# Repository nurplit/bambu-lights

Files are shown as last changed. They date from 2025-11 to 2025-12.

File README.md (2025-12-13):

# 🎨 Bambu Lights - Advanced LED Controller

An ESP32-based smart LED controller that brings your Bambu Lab 3D printer to life with dynamic status lighting. Features dual LED strip support, progress visualization beacon, smart chamber light control, and comprehensive printer state tracking via MQTT.

**Inspired by:** [BambuLights by judge2005](https://github.com/judge2005/BambuLights)




---

## 📺 Demo

### Beacon LED Effects
<p align="center">
  Progress Bar Effect
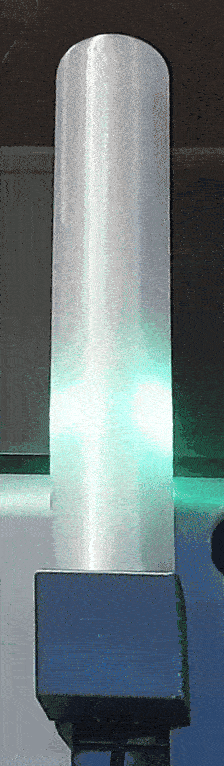
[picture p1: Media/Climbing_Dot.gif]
Climbing Dot Effect
  
  Beacon Animation
</p>

*Main LED strip demo coming soon!*

## ✨ Features

### � LED Control
- **Dual LED Strip Support** - Main status strip + optional progress beacon strip
- **Multiple Modes** - Auto-cycle, Manual color, Printer status, or Off
- **RGBW Support** - Optimized white channel for SK6812 RGBW LEDs
- **Custom Effects** - Solid, Blink, Breathe, Pulse, Progress Bar, Rainbow
- **Per-State Customization** - Different colors and effects for each printer state

### 📊 Printer Status Tracking
- **Real-time MQTT Integration** - Secure SSL/TLS connection to Bambu Lab printer
- **Comprehensive State Detection** - Idle, Heating, Printing, Paused, Complete, Error, Failed
- **Progress Visualization** - Progress bar effect shows print completion
- **Layer Tracking** - Displays current layer and total layers
- **Temperature Monitoring** - Bed and nozzle temperature display

### 🎯 Beacon LED Strip (Optional Second Strip)
- **Progress Bar Animation** - Fills from bottom to top with climbing pixel
- **Climbing Dot Effect** - Single LED climbs the strip
- **Gradient Fill** - Smooth color transition as print progresses
- **Pulsing Effect** - Breathing animation at current progress level
- **Heating Color Override** - Beacon uses heating color during warmup phase

### 🚪 Smart Automation
- **Door Detection** - Auto-responds to printer door open/close
- **Door Protection** - Prevents LED flicker during jogging with door open
- **Chamber Light Sync** - Controls printer chamber light based on printing color
- **LiDAR Pause** - Disables LEDs during LiDAR scanning to prevent interference
- **Auto-Off Timer** - Lights turn off X minutes after print completes (20-120 min)
- **Timelapse Detection** - Maintains proper lighting during timelapse recording

### 🌐 Web Interface
- **Modern Dark UI** - Beautiful responsive web interface with live updates
- **WiFiManager Integration** - Captive portal for easy first-time WiFi setup
- **OTA Updates** - Wireless firmware updates via mDNS hostname
- **Configuration Management** - All settings configurable via web UI
- **Serial Monitor** - Built-in web-based logging for debugging
- **Web Logs** - Access logs remotely at `http://your-device-ip/logs`
- **Telnet Support** - Remote serial monitoring via Telnet (port 23)
- **MQTT Debug Mode** - Toggle full payload logging for troubleshooting
- **Status Dashboard** - Real-time printer and system status display

## 🚀 Quick Start

### Hardware Requirements

#### Required Components
- **ESP32 Development Board** (ESP32-DevKitC, ESP32-WROOM-32, or compatible)
- **Addressable LED Strip** (WS2811, WS2812B, WS2813, SK6812, SK6812 RGBW, APA102, or APA106)
- **Power Supply** (5V DC, rated for your LED count - typically 60mA per LED at full white)
- **Jumper Wires** (3-4 wires depending on setup)

#### Optional Components
- **Second LED Strip** (Beacon progress visualization strip - same types as above)
  - **Recommended:** 10 pixels for optimal beacon effects
- **Logic Level Shifter** (if experiencing signal issues - 3.3V to 5V)
- **Capacitor** (1000µF, 6.3V or higher - smooths power fluctuations)

#### 3D Printed Enclosure
STL and Fusion 360 files included for ESP32 enclosure that mounts to the [BLV AMS Riser for X1C](https://makerworld.com/en/models/19535-blv-ams-ams-2-riser-for-x1c-p1s-p2s-v4#profileId-19420). Files located in `Enclosure/` folder.

### Wiring Diagram

#### Single LED Strip (Main Status)
```
ESP32 GPIO 2  ──→  LED Strip Data In
ESP32 GND     ──┐
                ├──→  LED Strip GND
Power Supply - ─┘
Power Supply + ────→  LED Strip VCC (5V)
```

#### Dual LED Strips (Main + Beacon)
```
ESP32 GPIO 2   ──→  Main LED Strip Data In
ESP32 GPIO 14  ──→  Beacon LED Strip Data In
ESP32 GND      ──┐
                 ├──→  Both LED Strips GND
Power Supply -  ─┘
Power Supply +  ────→  Both LED Strips VCC (5V)
```

> ⚠️ **Important:** Never power LED strips directly from ESP32 pins! Always use an external 5V power supply rated for your LED count. Connect all grounds together (ESP32 GND + LED GND + Power Supply GND).

### Installation

#### 1. Install PlatformIO
- Install [VS Code](https://code.visualstudio.com/)
- Install [PlatformIO IDE](https://platformio.org/platformio-ide) extension in VS Code

#### 2. Clone Repository
```bash
git clone https://github.com/YOUR_USERNAME/bambu-lights.git
cd bambu-lights
```

#### 3. Upload Filesystem (GIF Animations)
```bash
# Upload beacon animation GIFs to ESP32 filesystem
pio run --target uploadfs
```

#### 4. Flash Firmware
```bash
# Build and upload firmware
pio run --target upload

# Monitor serial output (optional)
pio device monitor
```

#### 5. First Boot Setup
1. ESP32 creates WiFi Access Point: `Bambu-Lights-XXXXXX`
2. Connect to this AP with your phone/computer
3. Captive portal opens automatically (or visit `192.168.4.1`)
4. Enter your WiFi SSID and password
5. Device connects and shows IP address in serial monitor

#### 6. Configure Printer
1. Open web browser to `http://bambu-lights-XXXXXX.local/` or the IP address
2. Click **Config** button
3. Enter your printer settings:
   - **Printer IP:** Your Bambu Lab printer's local IP address
   - **Access Code:** From Bambu Handy app (Settings → Lan Mode → Access Code)
   - **Serial Number:** From printer (Settings → Device → Serial Number)
4. Configure LED settings:
   - **Main LED Pin:** GPIO pin number (default: 2)
   - **LED Count:** Number of LEDs in your strip
   - **LED Type:** WS2811, WS2812B, WS2813, SK6812, SK6812 RGBW, APA102, or APA106
   - **Color Order:** GRB, RGB, etc. (depends on your LED type)
5. (Optional) Configure Beacon LED strip with same settings
6. Click **Save & Restart**

> 💡 **Tip:** Use the serial monitor to see connection status and debug any issues

## 🎛️ Web Interface

Access at `http://bambu-lights-XXXXXX.local/` or the IP shown in serial monitor.

### Mode Control
- **Printer Status Mode** - LEDs respond to printer state (Idle, Heating, Printing, Paused, Complete, Error)
- **Auto-Cycle Mode** - LEDs cycle through colors automatically
- **Manual Mode** - Set a custom solid color
- **Off Mode** - All LEDs off (timers and door lights still active)

### Printer Status LED Behavior
Customize colors, brightness, and effects for each printer state:
- **Idle** - Printer ready (default: blue)
- **Heating** - Bed/nozzle warming up (default: red)
- **Printing** - Active print (default: green)
- **Paused** - Print paused (default: yellow)
- **Complete** - Print finished (default: white)
- **Error** - Printer error (default: red blink)

Each state supports multiple effects:
- Solid, Blink, Breathe, Pulse, Progress Bar, Rainbow

### Beacon Settings (Optional Second Strip)
- **Enable/Disable** - Toggle beacon LED strip
- **Effect Selection** - Progress Bar, Climbing Dot, Gradient Fill, Pulsing
- **Color Customization** - Start color, end color (gradient), climb color
- **Brightness Control** - Independent brightness setting
- **GPIO Pin** - Configurable pin assignment

### Quick Controls
- **Door Lights** - Auto white lights when door opens (configurable color)
- **Chamber Light Sync** - Controls printer chamber light:
  - Auto-on during timelapse recording
  - Smart control: ON for white printing colors, OFF for colored filaments
- **LiDAR Pause** - Turns off LEDs during LiDAR scanning
- **Auto-Off Timer** - Lights turn off X minutes after print completes
  - Timer starts when print finishes
  - Lights stay on during active printing
  - Timer restarts if door opened

### System Status
Real-time display of:
- ESP32 WiFi signal, uptime, free memory
- MQTT connection status
- Current LED mode and settings
- Printer state (online/offline, temperatures, progress, layer count)
- Door status
- Timer status (active/inactive, time remaining)

### Serial Monitor & Remote Logging
Built-in logging accessible three ways:

1. **Web Interface** - Serial monitor panel on main page with auto-refresh
2. **Direct URL** - Access logs at `http://your-device-ip/logs` via any browser
3. **Telnet** - Connect via Telnet for real-time streaming logs:
   ```bash
   telnet your-device-ip 23
   ```

Logged events include:
- Connection events
- MQTT messages
- State changes
- Error messages
- Toggle MQTT debug mode for full payload logging (15KB+ per message)

## � Advanced Features

### Smart Chamber Light Control
The system intelligently manages your printer's chamber light:
- **Timelapse Mode** - Auto-on during timelapse recording
- **Color-Aware Control** - Prevents chamber light from washing out custom LED colors:
  - **White filament (255,255,255)** → Chamber light ON
  - **Colored filament** → Chamber light OFF
- **Dynamic Updates** - Responds to printing color changes mid-print

### Door Open Protection
Sophisticated door detection with multiple benefits:
- **Bidirectional Detection** - Accurately tracks door open AND close states
- **Flicker Prevention** - LEDs don't change during jogging operations with door open
- **Automatic Restoration** - LEDs restore to printer state when door closes
- **Timer Integration** - Auto-off timer restarts when door opened

### Progress Beacon Animations
Four unique visualization effects for the optional beacon strip:

1. **Progress Bar** - Green bar fills from bottom to top with white climbing pixel
2. **Climbing Dot** - Single LED climbs up the strip
3. **Gradient Fill** - Smooth color transition (customizable start/end colors)
4. **Pulsing** - Breathing animation at current progress level

All effects show real-time print progress and automatically adapt to heating/printing states.

### RGBW LED Optimization
Special support for SK6812 RGBW LEDs:
- Dedicated white channel for true white output
- Automatic RGBW pixel allocation
- Optimized memory usage for large LED counts

---

## 📊 Technical Details

### System Requirements
- **ESP32**: ESP32-DevKitC or compatible (240MHz dual-core, 320KB RAM, 4MB Flash minimum)
- **Memory**: ~120KB free RAM during operation
- **Power**: 5V/2A minimum for small setups, calculate 60mA per LED at full white for larger installations
- **Network**: 2.4GHz WiFi (ESP32 doesn't support 5GHz)

### Performance Specifications
- **LED Update Rate**: 30 FPS
- **MQTT Latency**: <500ms typical response time
- **Web Interface Load Time**: 2-5 seconds
- **Memory Management**: Chunked HTTP transfer prevents fragmentation
- **Uptime**: Stable operation for weeks with proper power supply

### Supported LED Types
- **WS2811** (RGB) - 5V LED strips, common in older/budget setups
- **WS2812B** (RGB) - Most common, affordable, integrated controller
- **WS2813** (RGB) - Backup data line for reliability
- **SK6812** (RGB or RGBW) - Better color accuracy, true white with RGBW
- **APA102** (RGB) - SPI-based, faster refresh rates
- **APA106** (RGB) - Alternative to WS2812B

### Color Order Options
Configure in web interface to match your specific LED strip:
- GRB (most common for WS2812B)
- RGB
- BGR
- BRG
- RBG
- GBR

---

## 🐛 Troubleshooting

### LEDs Not Responding
**Symptoms:** LEDs stay off or show wrong colors

**Solutions:**
1. Check wiring:
   - ESP32 GND → LED Strip GND → Power Supply GND (all connected)
   - ESP32 GPIO pin → LED Strip Data In
   - Power Supply 5V → LED Strip VCC
2. Verify power supply capacity (60mA × LED count)
3. Try different color order setting (web config → LED Settings)
4. Use logic level shifter if LED strip requires 5V data signal
5. Add 470Ω resistor between ESP32 GPIO and LED data line
6. Add 1000µF capacitor between LED VCC and GND

### WiFi Connection Issues
**Symptoms:** Can't connect to WiFi, AP mode doesn't appear

**Solutions:**
1. Ensure WiFi network is 2.4GHz (ESP32 doesn't support 5GHz)
2. Check WiFi credentials in serial monitor
3. Factory reset: Hold GPIO 0 button during boot for 5 seconds
4. Look for AP: `Bambu-Lights-XXXXXX` (last 6 chars of MAC address)
5. Strong WiFi signal required - ESP32 antenna is small
6. Restart router if connection fails repeatedly

### MQTT Connection Failures
**Symptoms:** "MQTT disconnected" in serial monitor, printer status not updating

**Solutions:**
1. Verify printer IP address is correct (check router DHCP)
2. Confirm access code from Bambu Handy app (Settings → LAN Mode)
3. Ensure printer serial number is accurate (Settings → Device)
4. Check printer is on same network as ESP32
5. Enable LAN Mode on printer if not already enabled
6. Printer must be powered on and connected to WiFi
7. Check firewall isn't blocking port 8883 (MQTT SSL)

### Web Interface Problems
**Symptoms:** Page won't load, hangs, or shows errors

**Solutions:**
1. Try IP address instead of mDNS hostname
2. Find IP in serial monitor: `IP: 192.168.x.x`
3. Clear browser cache (Ctrl+Shift+Del)
4. Try different browser (Chrome/Firefox recommended)
5. Disable browser extensions that might interfere
6. Check ESP32 free memory in status panel (should be >100KB)
7. Reboot ESP32 if memory is low

### Memory Issues
**Symptoms:** ESP32 reboots, crashes, or web interface slow

**Solutions:**
1. Check free memory in web interface status panel
2. Reduce LED count if using very large strips (>300 LEDs)
3. Disable MQTT debug mode (uses significant memory)
4. Reboot ESP32 to clear fragmentation
5. Verify firmware was compiled with correct partition scheme

### Wrong Colors or Glitches
**Symptoms:** Colors are wrong, flickering, or random patterns

**Solutions:**
1. Try different color order in web config (GRB, RGB, etc.)
2. Add 470Ω resistor between ESP32 and LED data line
3. Shorten data wire if longer than 1 meter
4. Use shielded wire for data line in electrically noisy environments
5. Check power supply voltage (should be 5.0V ±0.5V)
6. Verify power and ground are connected to BOTH ends of long LED strips

### OTA Update Failures
**Symptoms:** Firmware upload fails or times out

**Solutions:**
1. Ensure ESP32 and computer are on same network
2. Use mDNS hostname: `bambu-lights-XXXXXX.local`
3. Disable firewall temporarily during upload
4. Try USB upload instead: `pio run --target upload`
5. Increase OTA timeout in platformio.ini if on slow network

### Serial Monitor Output
Normal startup sequence (viewable via Serial, Telnet, or `/logs`):
```
=== Bambu Lights Controller ===
Chip: ESP32-D0WDQ6 (revision 1)
Free Memory: 296504 bytes
WiFi connecting...
WiFi connected! IP: 192.168.0.163
mDNS started: bambu-lights-123456.local
Telnet server started on port 23
Starting MQTT connection...
MQTT connected successfully!
```

**Access Logs:**
- **USB Serial:** Connect via USB, 115200 baud
- **Telnet:** `telnet 192.168.0.163 23` (use your device IP)
- **Web Browser:** `http://192.168.0.163/logs` (use your device IP)

Error indicators:
- `WiFi connection failed` - Check SSID/password
- `MQTT connection failed` - Check printer IP/access code
- `Low memory warning` - Reduce LED count or features
- `LED initialization failed` - Check GPIO pin and LED type

---

## 🏠 Home Automation Integration

### Home Assistant MQTT Discovery (Auto-Configuration)

**NEW!** Bambu Lights now supports **Home Assistant MQTT Discovery** - sensors auto-appear in Home Assistant with zero manual configuration!

#### Quick Setup (3 Steps)
1. **Configure in Web UI:**
   - Open web interface: `http://192.168.0.163`
   - Click **Config** button
   - Scroll to **Home Assistant MQTT** section
   - Enable and enter your HA MQTT broker details:
     * **HA MQTT Broker:** Your Home Assistant IP (e.g., `192.168.0.50`)
     * **Port:** Usually `1883` (non-SSL)
     * **Username/Password:** Optional (if broker requires auth)
     * **Discovery Prefix:** Default `homeassistant` (leave unchanged)
   - Click **Save HA MQTT Settings**

2. **Check Home Assistant:**
   - Go to **Settings → Devices & Services → MQTT**
   - You'll see a new device: **Bambu Lights**
   - Automatically created sensors:
     * `sensor.bambu_lights_printer_state` (IDLE, RUNNING, FINISH, etc.)
     * `sensor.bambu_lights_print_progress` (0-100%)
     * `sensor.bambu_lights_bed_temperature` (°C)
     * `sensor.bambu_lights_nozzle_temperature` (°C)
     * `sensor.bambu_lights_current_layer` (layer X/Y)
     * `sensor.bambu_lights_current_file` (filename)
     * `binary_sensor.bambu_lights_printing` (ON/OFF)

3. **Create Automations:**
   - Drag sensors into automation editor
   - No YAML needed - fully visual!

#### Why Use This for Notifications?

**For Bambu Lab Printers in LAN-Only Mode:**

If you're running your Bambu Lab printer in **LAN-only mode** (not connected to Bambu Cloud), you lose access to the official Bambu Handy app's push notifications for print completion, errors, and status updates. 

**Bambu Lights MQTT integration solves this!** By publishing real-time printer status to your home automation system, you can create your own notification system with:
- **Push Notifications** to your phone (iOS/Android apps)
- **SMS/Text Messages** via services like Twilio
- **Email Alerts** for print completion or failures
- **Voice Announcements** via Alexa, Google Home, or smart speakers (TTS)
- **Smart Home Triggers** like turning on lights, sending Discord/Slack messages, etc.

All of this works **completely offline** on your local network - no cloud connection required!

#### Example Automations

**Print Complete Notification (Alexa TTS):**
```yaml
alias: "Bambu Print Complete - Alexa Announcement"
trigger:
  - platform: state
    entity_id: sensor.bambu_lights_printer_state
    to: "FINISH"
action:
  - service: notify.alexa_media
    data:
      target:
        - media_player.office_echo
      message: "Your 3D print is complete! {{ states('sensor.bambu_lights_current_file') }} finished printing."
```

**Phone Notification When Print Finishes:**
```yaml
alias: "Bambu Print Complete - Push Notification"
trigger:
  - platform: state
    entity_id: sensor.bambu_lights_printer_state
    to: "FINISH"
action:
  - service: notify.mobile_app_iphone
    data:
      title: "3D Print Complete!"
      message: "{{ states('sensor.bambu_lights_current_file') }} - {{ states('sensor.bambu_lights_print_progress') }}%"
```

**Turn on Room Lights When Print Starts:**
```yaml
alias: "Bambu Print Started - Office Lights On"
trigger:
  - platform: state
    entity_id: binary_sensor.bambu_lights_printing
    to: "on"
action:
  - service: light.turn_on
    target:
      entity_id: light.office_ceiling
    data:
      brightness: 255
```

**Progress Bar Dashboard Card:**
```yaml
type: gauge
entity: sensor.bambu_lights_print_progress
name: Print Progress
unit: "%"
min: 0
max: 100
```

#### Architecture
- **Dual MQTT Connections:** ESP32 maintains two separate MQTT broker connections:
  1. **Printer MQTT** (SSL 8883): Subscribes to Bambu Lab printer status
  2. **Home Assistant MQTT** (1883): Publishes sensor states for HA

- **Real-Time Updates:** State changes trigger immediate sensor updates (throttled to max 1/sec)
- **Auto-Discovery:** Uses MQTT Discovery protocol - entities appear automatically in HA
- **No Cloud Required:** Everything runs locally on your network

#### Troubleshooting
- **Sensors not appearing?**
  * Check HA MQTT broker is running (Settings → Add-ons → Mosquitto broker)
  * Verify broker IP/port in Config page
  * Check ESP32 logs via Telnet: `telnet 192.168.0.163`
  * Look for "HA MQTT connected successfully!" message

- **Connection failed?**
  * Most HA MQTT brokers use port **1883 without SSL**
  * If using SSL (port 8883), enable "Use SSL/TLS for HA broker" checkbox
  * Username/password only needed if you configured auth in Mosquitto

### OpenHAB / Other Home Automation Systems

For systems without MQTT Discovery support, use the **HTTP API**:

**Option 1: HTTP API (Available Now)**
Use HTTP POST requests to control the device via the web interface:
```bash
# OpenHAB HTTP Binding Example
# Turn lights to specific color (mode=1, manual mode)
curl -X POST http://192.168.0.163/save \
  -d "currentMode=1&currentColor=%23FF0000&brightness=100"

# Turn off lights (mode=3)
curl -X POST http://192.168.0.163/save \
  -d "currentMode=3"

# Switch to printer mode (mode=0)
curl -X POST http://192.168.0.163/save \
  -d "currentMode=0"
```

**Option 2: MQTT Commands (Feature Request)**
Future enhancement could add command subscription topics like:
```
bambu-lights/command/mode          # 0=printer, 1=manual, 2=auto-cycle, 3=off
bambu-lights/command/color         # Hex color code (e.g., FF0000)
bambu-lights/command/brightness    # 0-100
bambu-lights/command/effect        # solid, blink, breathe, pulse, rainbow
```

**OpenHAB Example Configuration (HTTP):**
```
Thing http:url:bambuLights "Bambu Lights" [
    baseURL="http://192.168.0.163",
    refresh=30
] {
    Channels:
        Type switch : power "Power" [
            onValue="POST:/save:currentMode=0",
            offValue="POST:/save:currentMode=3"
        ]
        Type color : color "Color" [
            commandExtension="POST:/save?currentMode=1&currentColor=%s"
        ]
}
```

**Home Assistant Example (HTTP - Legacy):**
```yaml
rest_command:
  bambu_lights_on:
    url: "http://192.168.0.163/save"
    method: POST
    payload: "currentMode=0"
  
  bambu_lights_off:
    url: "http://192.168.0.163/save"
    method: POST
    payload: "currentMode=3"
```

**Node-RED Example:**
Use HTTP Request node to POST to `/save` endpoint with appropriate parameters.

> 💡 **Tip:** Use MQTT Discovery for Home Assistant (see above) - it's much easier than HTTP API!

> 🔧 **Want MQTT control?** This would be a great community contribution! Add subscription to `bambu-lights/command/#` topics in the `connectToMQTT()` function.

---

## ❓ FAQ

### Q: How many LEDs can I control?
**A:** Tested stable with 300 LEDs on single strip. Hardware limit is ~1000 LEDs, but practical limit depends on memory available. RGBW uses more memory than RGB.

### Q: Can I control multiple printers?
**A:** Currently supports one printer per ESP32. For multiple printers, use multiple ESP32 boards or wait for future multi-printer support.

### Q: Do I need the beacon LED strip?
**A:** No, beacon strip is optional. Main LED strip alone provides full printer status visualization. Beacon adds progress visualization.

### Q: What's the difference between SK6812 RGB and RGBW?
**A:** RGBW has dedicated white LED for true white color. RGB mixes red+green+blue for white, which looks slightly blue/pink. RGBW recommended for better color accuracy.

### Q: Can I use longer wires between ESP32 and LEDs?
**A:** Keep data wire under 1 meter for best results. For longer distances, use differential signaling (SPI LEDs) or repeater/buffer chips.

### Q: Does this work with Bambu Lab P1P, P1S, X1C, A1?
**A:** Yes! Works with all Bambu Lab printers that support LAN Mode and MQTT. Requires access code from Bambu Handy app.

### Q: How do I find my printer's IP address?
**A:** Check your router's DHCP client list or use Bambu Handy app (Settings → Network). Most routers show connected devices.

### Q: What happens if WiFi disconnects?
**A:** ESP32 automatically reconnects. LEDs continue last pattern until reconnected. No settings are lost (stored in flash).

### Q: Can I add custom LED effects?
**A:** Yes! Code is open-source. Add your effect to `handleAnimations()` function in `src/main.cpp`. Contributions welcome!

### Q: How much power does this use?
**A:** ESP32: ~500mA. LEDs: ~60mA each at full white. 36 LEDs at full white = ~2.7A total. Typical printing use is 30-50% brightness = ~1-1.5A.

### Q: Can I 3D print an enclosure?
**A:** Recommended! Keep ESP32 cool and protect from shorts. Mount near printer but away from heated bed. Plenty of ESP32 enclosure designs on Thingiverse/Printables.

---

## 🤝 Contributing

Contributions are welcome! This project thrives on community input.

### How to Contribute

**Report Bugs:**
1. Check existing [GitHub Issues](../../issues) first
2. Create new issue with clear title
3. Include:
   - Hardware setup (ESP32 model, LED type/count)
   - Firmware version
   - Serial monitor output
   - Steps to reproduce
   - Expected vs actual behavior

**Suggest Features:**
1. Check existing [GitHub Discussions](../../discussions)
2. Describe use case and benefits
3. Include mockups/diagrams if applicable

**Submit Code:**
1. Fork the repository
2. Create feature branch: `git checkout -b feature-amazing-effect`
3. Follow existing code style (4 spaces, descriptive variables)
4. Test on real hardware with various LED counts
5. Update README.md if adding features
6. Commit with clear messages: `git commit -m "Add rainbow spiral effect"`
7. Push to your fork: `git push origin feature-amazing-effect`
8. Open Pull Request with detailed description

### Development Setup
```bash
# Clone your fork
git clone https://github.com/YOUR_USERNAME/bambu-lights.git
cd bambu-lights

# Create branch
git checkout -b my-new-feature

# Build and test
pio run --target upload
pio device monitor

# Make changes, test thoroughly

# Commit
git add .
git commit -m "Descriptive message"
git push origin my-new-feature
```

### Code Standards
- **Formatting:** 4 spaces, no tabs
- **Naming:** `camelCase` for variables, `UPPER_CASE` for constants
- **Comments:** Explain WHY, not WHAT
- **Memory:** Avoid String class, use char arrays
- **Testing:** Test with 10, 50, 100+ LED configurations

---

## 📜 License

This project is licensed under the **MIT License**.

```
MIT License

Copyright (c) 2024 Bambu Lights Contributors

Permission is hereby granted, free of charge, to any person obtaining a copy
of this software and associated documentation files (the "Software"), to deal
in the Software without restriction, including without limitation the rights
to use, copy, modify, merge, publish, distribute, sublicense, and/or sell
copies of the Software, and to permit persons to whom the Software is
furnished to do so, subject to the following conditions:

The above copyright notice and this permission notice shall be included in all
copies or substantial portions of the Software.

THE SOFTWARE IS PROVIDED "AS IS", WITHOUT WARRANTY OF ANY KIND, EXPRESS OR
IMPLIED, INCLUDING BUT NOT LIMITED TO THE WARRANTIES OF MERCHANTABILITY,
FITNESS FOR A PARTICULAR PURPOSE AND NONINFRINGEMENT. IN NO EVENT SHALL THE
AUTHORS OR COPYRIGHT HOLDERS BE LIABLE FOR ANY CLAIM, DAMAGES OR OTHER
LIABILITY, WHETHER IN AN ACTION OF CONTRACT, TORT OR OTHERWISE, ARISING FROM,
OUT OF OR IN CONNECTION WITH THE SOFTWARE OR THE USE OR OTHER DEALINGS IN THE
SOFTWARE.
```

See [LICENSE](LICENSE) file for full details.

---

## 🙏 Acknowledgments

This project stands on the shoulders of giants:

### Core Inspiration
- **[BambuLights](https://github.com/judge2005/BambuLights)** by **judge2005** - Original concept, MQTT integration patterns, and beacon LED visualization. This project wouldn't exist without this pioneering work!

### Additional Inspiration
- **[BLLED Controller](https://github.com/DutchDevelop/BLLEDController)** - LED control patterns and status visualization ideas

### Key Libraries
- **[Adafruit_NeoPixel](https://github.com/adafruit/Adafruit_NeoPixel)** - Robust LED strip control
- **[PubSubClient](https://github.com/knolleary/pubsubclient)** - Reliable MQTT communication
- **[WiFiManager](https://github.com/tzapu/WiFiManager)** - Seamless WiFi configuration
- **[ArduinoJson](https://github.com/bblanchon/ArduinoJson)** - Efficient JSON parsing
- **[AsyncTCP](https://github.com/me-no-dev/AsyncTCP)** + **[ESPAsyncWebServer](https://github.com/me-no-dev/ESPAsyncWebServer)** - Fast web interface

### Community
- ESP32 Arduino framework maintainers
- PlatformIO team for excellent tooling
- Bambu Lab for creating amazing printers with open MQTT API
- All contributors and users who report bugs and suggest features

### Special Thanks
- 3D printing community for inspiration and support
- Everyone who shares their builds and improvements

---

## 📞 Support

### Get Help
- **Issues**: [GitHub Issues](../../issues) - Bug reports and technical problems
- **Discussions**: [GitHub Discussions](../../discussions) - Questions, ideas, and general chat
- **Documentation**: This README and code comments

### Quick Links
- [Installation Guide](#-installation) - Step-by-step setup
- [Troubleshooting](#-troubleshooting) - Common problems and solutions  
- [FAQ](#-faq) - Frequently asked questions
- [Contributing](#-contributing) - How to help improve this project

### Response Time
This is a community project maintained by volunteers. Please be patient - we'll respond as soon as we can!

---

**⭐ If this project helped you, please star the repository and share it with other Bambu Lab users!**

**Made with ❤️ for the 3D printing community**

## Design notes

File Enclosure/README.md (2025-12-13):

# 🔧 ESP32 Enclosure for Bambu Lights

## Overview

Custom 3D printed enclosure designed to mount on the [BLV AMS Riser for X1C/P1S/P2S](https://makerworld.com/en/models/19535-blv-ams-ams-2-riser-for-x1c-p1s-p2s-v4#profileId-19420).

## Files Included

### STL Files (Print-Ready)
- `ESP32_Enclosure_Main.stl` - Main enclosure body
- `ESP32_Enclosure_Lid.stl` - Lid with ventilation
- `Beacon_Mount_10LED.stl` - Mount for 10-pixel beacon LED strip

### Source Files (Editable)
- `Bambu_Lights_Enclosure.f3d` - Fusion 360 project file
  - Fully parametric design
  - Easy to modify for different ESP32 boards or mounting solutions

## Print Settings

**Recommended:**
- **Material:** PETG or ABS (for heat resistance near printer)
- **Layer Height:** 0.2mm
- **Infill:** 20%
- **Supports:** Required for lid ventilation slots
- **Orientation:** Print main body upside down

**Notes:**
- No supports needed for main body if printed upside down
- Lid requires supports for ventilation grilles
- Test fit before final assembly

## Assembly

1. Insert ESP32 board into main enclosure
2. Route LED strip wires through cable management slots
3. Mount beacon LED strip (10 pixels recommended) to beacon mount
4. Secure lid with M3 screws (optional - can snap fit)
5. Mount assembled unit to AMS riser using provided mounting holes

## Mounting to AMS Riser

The enclosure is designed to bolt directly to the BLV AMS Riser:
- **Hardware:** 2x M3x8mm screws
- **Position:** Side mount for easy access to USB port
- **Cable routing:** Integrated channels for clean wire management

## Customization

### Editing in Fusion 360
1. Open `Bambu_Lights_Enclosure.f3d` in Fusion 360
2. Modify parameters in the "User Parameters" section:
   - `board_width` - ESP32 board width
   - `board_length` - ESP32 board length
   - `wall_thickness` - Enclosure wall thickness
   - `ventilation_slot_width` - Adjust airflow
3. Update and export new STL files

### Common Modifications
- **Different ESP32 board:** Adjust board dimensions in parameters
- **Larger beacon:** Modify `Beacon_Mount_10LED.stl` for more LEDs
- **Alternative mounting:** Edit mounting hole positions

## Tips

- **Airflow:** Keep ventilation slots clear for ESP32 cooling
- **Wire management:** Use provided cable channels to prevent interference with printer
- **Beacon placement:** Position for clear visibility from front of printer
- **USB access:** Enclosure designed for easy access to USB port for updates

## License

These files are released under the same MIT License as the main project. Feel free to modify and share!

## Credits

Designed to complement the [BLV AMS Riser](https://makerworld.com/en/models/19535) by BLV.

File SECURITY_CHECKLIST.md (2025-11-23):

# Security Notice

✅ **GOOD NEWS: WiFi credentials are NO LONGER hardcoded!**

This project now uses WiFiManager for automatic WiFi setup via captive portal. No WiFi credentials are stored in the code!

## ⚠️ Still Check These:

### src/main.cpp
The MQTT/Printer default values should be placeholders:

```cpp
// Line ~27-29: MQTT/Printer Default Values
String mqtt_password = "your_access_code";    // ✅ Generic placeholder (OK)
String device_serial = "01S00A123456789";     // ✅ Generic placeholder (OK)  
String mqtt_server = "192.168.0.100";         // ⚠️ Check this isn't YOUR real printer IP
```

## Recommended: Verify Placeholders

The code should have generic placeholders like this:

```cpp
// WiFi - Handled by WiFiManager (no hardcoded credentials!)
WiFiManager wifiManager;                      // ✅ GOOD

// MQTT defaults (configured via web interface)
String mqtt_server = "192.168.1.100";         // Generic local IP
String mqtt_password = "your_access_code";    // Placeholder
String device_serial = "01S00A301234567";     // Generic serial
```

## After Securing Credentials:

1. Review all code files for any other sensitive information
2. Check commit history - if you've already committed credentials, you'll need to:
   - Either start with a fresh repository (recommended)
   - Or use git tools to remove sensitive data from history

## Safe to Commit:

✅ Hardware schematics  
✅ PIN configurations  
✅ LED settings  
✅ Code logic and algorithms  
✅ Web interface HTML/CSS/JS  

## Never Commit:

❌ WiFi passwords  
❌ MQTT access codes  
❌ API keys  
❌ Device serial numbers (can be used to identify/access your printer)  
❌ IP addresses of your local network devices  

---

**Ready to commit?** Delete this file after you've secured your credentials!

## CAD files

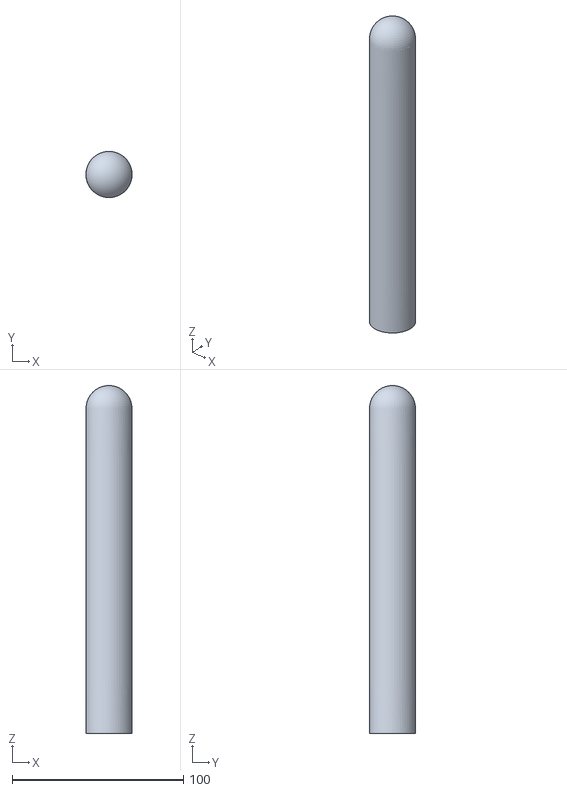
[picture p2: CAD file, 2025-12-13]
Enclosure/10 led cover.stl
27.0 x 27.0 x 203.4

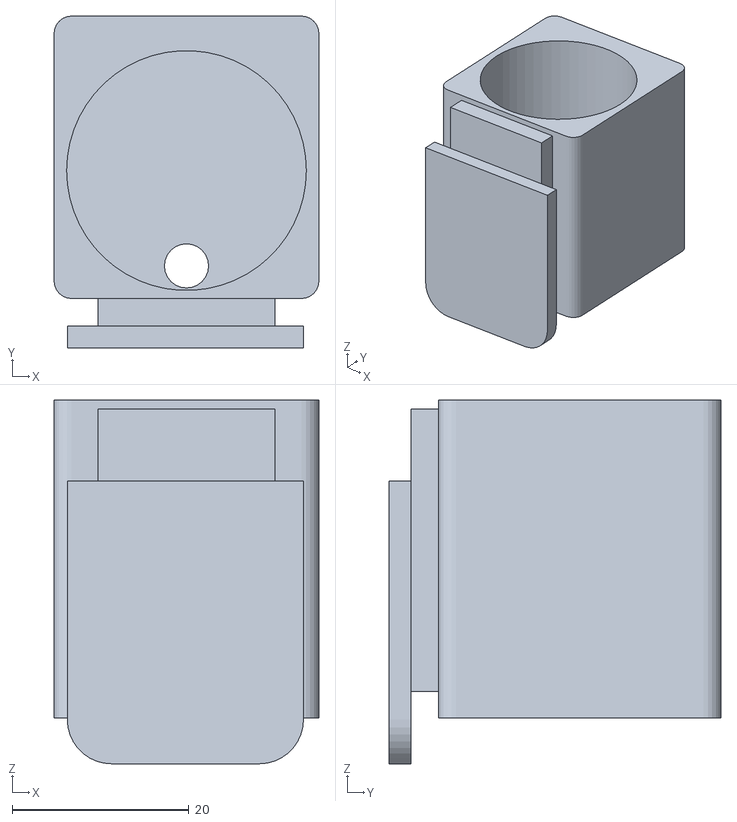
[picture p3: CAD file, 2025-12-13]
Enclosure/10 led holder fits ams riser.stl
30.0 x 37.6 x 41.2

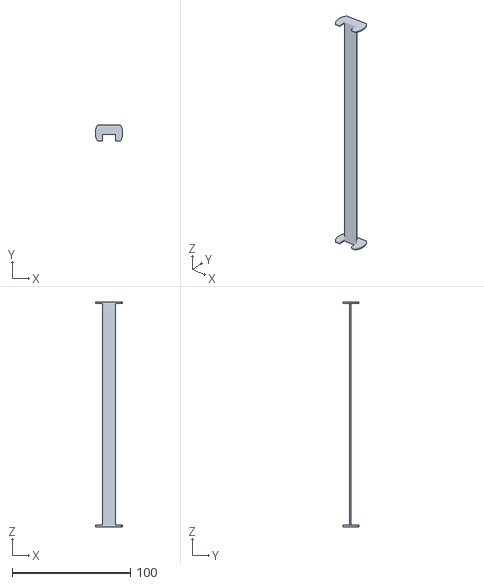
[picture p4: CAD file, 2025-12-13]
Enclosure/10 led insert holder.stl
23.2 x 13.8 x 190.3

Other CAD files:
Enclosure/Beacon.f3d

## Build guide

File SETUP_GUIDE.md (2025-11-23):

# Getting Your Bambu Lab Printer Credentials

To connect this controller to your Bambu Lab printer, you'll need three pieces of information:

## 1. Printer IP Address

**Method 1: From Printer Screen**
- On the printer touchscreen: Settings → Network → IP Address

**Method 2: From Router**
- Check your router's DHCP client list
- Look for a device named similar to your printer model (e.g., "BambuLab-X1C")

**Method 3: From Bambu Studio**
- Open Bambu Studio
- Look at the printer connection info
- The IP address is shown in the printer selection dialog

## 2. Access Code

The access code is a password that allows MQTT access to your printer.

**How to Get It:**
1. Download **Bambu Handy** app on your phone (iOS/Android)
2. Connect to your printer in the app
3. Go to: **Settings** → **General** → **Access Code**
4. You'll see a code like: `12345678`
5. Copy this code - you'll use it as the MQTT password

**Note:** The access code is the same for all MQTT clients connecting to your printer. Keep it secure!

## 3. Device Serial Number

Your printer's unique serial number.

**Method 1: From Printer**
- On the printer touchscreen: Settings → About → Serial Number
- Format: `01S00A301423` (example)

**Method 2: From Bambu Studio**
- Open Bambu Studio
- Look at printer properties
- Serial number is listed in the device information

**Method 3: Physical Label**
- Check the label on the back or bottom of your printer
- Look for "S/N:" followed by the serial number

## 4. Configure in the Code

Edit `src/main.cpp` and update these lines:

```cpp
// Line ~27: Your printer's IP address
String mqtt_server = "192.168.0.100";  // ⚠️ CHANGE THIS

// Line ~28: Access code from Bambu Handy app
String mqtt_password = "12345678";     // ⚠️ CHANGE THIS

// Line ~29: Your printer's serial number
String device_serial = "01S00A301423"; // ⚠️ CHANGE THIS
```

## 5. Alternative: Configure via Web Interface

After first boot, you can also configure these settings through the web interface:
1. Upload the firmware with just WiFi credentials set
2. Access the web interface
3. Go to **Config** tab
4. Enter MQTT settings and save

## MQTT Topics

The controller subscribes to:
```
device/{YOUR_SERIAL_NUMBER}/report
```

This is the standard Bambu Lab MQTT topic that contains:
- Print progress
- Printer state (IDLE, RUNNING, PAUSE, FINISH, FAILED)
- Temperatures (bed, nozzle, chamber)
- Chamber light status
- Door status (via home_flag)
- Stage information (printing, heating, etc.)

## Security Notes

⚠️ **Important:**
- Your access code grants MQTT access to your printer
- Don't share your access code publicly
- Don't commit code with real credentials to public repositories
- Use placeholder values in public code

## Troubleshooting

**Can't connect to MQTT?**
- Verify printer IP is correct (ping it from command line)
- Verify access code is entered correctly (no spaces)
- Verify serial number format is correct
- Check that printer is powered on and connected to network
- Try port 8883 (SSL) or 1883 (non-SSL) depending on your printer model

**Need more help?**
- Check the [GitHub Issues](../../issues)
- Review serial monitor output for connection errors
- Enable debug logging in the web interface

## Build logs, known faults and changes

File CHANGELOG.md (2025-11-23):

# Changelog - Bambu Lights Controller

## Recent Updates (November 16, 2025)

### Features Added

#### 1. Gradient End Color Feature
- Added gradient end color configuration for gradient effect
- New settings in LED behavior configuration:
  - Gradient start color (existing)
  - Gradient end color (new)
- Force update mechanism to immediately apply gradient changes
- Affects: Heating, First Layer, and any other states using gradient effect

#### 2. SK6812 RGBW White Channel Optimization
- Implemented proper RGBW (4-channel) LED support for SK6812 strips
- Added automatic white channel detection when `led_type = "SK6812"`
- Smart white channel optimization:
  - When RGB values are equal (e.g., 255,255,255 for white), the firmware automatically uses only the dedicated white channel
  - Provides more efficient power usage and purer white color
- Separate RGBW data structures and arrays:
  - `RGBW` struct with r, g, b, w fields
  - `RGBW* rgbw_leds` array for 4-channel LEDs
  - `RGB* leds` array for 3-channel LEDs
- Updated functions:
  - `setLED()` - Routes to correct array based on `is_rgbw` flag
  - `rgbToRMT()` - Handles 32-bit RGBW data vs 24-bit RGB data
  - `updateLEDs()` - Checks `is_rgbw` to use correct data
  - `applyColorOrder()` - Supports GRBW byte order for SK6812
  - `reallocateLEDs()` - Allocates RGBW array when needed

#### 3. Beacon LED Hardware Settings
- Added RGBW checkbox for beacon LED strip configuration
- Separate configuration from main LED strip
- Label: "RGBW LEDs (4-channel with white - check this if colors are wrong)"
- Beacon uses its own `beacon_is_rgbw` flag

#### 4. Dynamic Beacon GIF Animations
- Enlarged beacon GIF preview from 280px to 480x480px for better visibility
- Implemented dynamic GIF switching based on selected beacon effect:
  - Progress Bar → `Progress_Bar.gif` (shows green bar + white climbing dot)
  - Climbing Dot → `Climbing_Dot.gif` (white dot with trail)
  - Gradient Fill → `Gradient_Fill.gif` (green-to-red gradient)
  - Pulsing Dot → `Pulsing_Dot.gif` (blue breathing dot)
- Created Python script (`generate_beacon_gifs.py`) to generate all 4 beacon effect animations
- Total GIF size: ~51KB (optimized for ESP32 filesystem)
- JavaScript function order fix: Moved `autoSaveBeacon()` definition before HTML that calls it

#### 5. Mode-Based LED Update Control
- **CRITICAL FIX**: MQTT updates and web handlers now respect current mode
- LED updates only apply printer state when in **PRINTER mode**
- Prevents printer state from interfering with:
  - **MANUAL mode**: User-selected colors stay stable
  - **AUTO mode**: Color cycling continues smoothly
  - **OFF mode**: LEDs stay off
- Updated functions:
  - `onMqttMessage()` - Only calls `updatePrinterLEDs()` if in PRINTER mode
  - `handleDoorTrigger()` - Only updates LEDs if in PRINTER mode
  - `handleLidarLightsOff()` - Only updates LEDs if in PRINTER mode
  - Main loop - Only calls `updatePrinterLEDs()` if in PRINTER mode

#### 6. Door Open Protection During Jogging
- When door is open in PRINTER mode, LED updates are paused
- Prevents jogging commands from causing LED color flickering
- LEDs maintain their current color while door is open
- Normal printer state updates resume when door closes
- Logic: Skip `updatePrinterLEDs()` when `door_is_open == true`

### Code Structure Changes

#### Memory Management
- Proper allocation/deallocation for both RGB and RGBW arrays
- `reallocateLEDs()` now handles both LED types
- Cleanup in `reallocateLEDs()`:
  ```cpp
  if (leds) delete[] leds;
  if (rgbw_leds) delete[] rgbw_leds;
  if (led_data) delete[] led_data;
  ```

#### Data Structures
```cpp
struct RGBW {
    uint8_t r, g, b, w;
};

RGB* leds = nullptr;           // 3-channel LEDs
RGBW* rgbw_leds = nullptr;     // 4-channel LEDs
bool is_rgbw = false;          // Main LED type flag
bool beacon_is_rgbw = false;   // Beacon LED type flag
```

#### LED Type Detection
```cpp
// Automatic RGBW detection based on LED type
is_rgbw = (led_type == "SK6812");
```

### Bug Fixes

1. **JavaScript Function Order**: Fixed `autoSaveBeacon()` not defined error by moving function definition before HTML
2. **MQTT Override**: Fixed printer state overriding Manual/Auto modes
3. **Jogging Flicker**: Fixed LED color changing during print head jogging with door open
4. **RGBW Allocation**: Fixed missing RGBW array allocation causing white channel not to work
5. **Progress Bar GIF**: Updated to show both colors (green progress bar + white climbing dot)

### File Structure

#### New Files
- `generate_beacon_gifs.py` - Python script to generate beacon effect animations
- `data/Progress_Bar.gif` (5.2 KB)
- `data/Climbing_Dot.gif` (21.77 KB)
- `data/Gradient_Fill.gif` (6.76 KB)
- `data/Pulsing_Dot.gif` (17.8 KB)

#### Modified Files
- `src/main.cpp` - Core firmware with all updates (~4810 lines)
- `platformio.ini` - Using default.csv partition (1.5MB filesystem)

### Configuration

#### LED Strip Settings
- **LED Type**: Dropdown includes "SK6812 (RGBW Compatible)" option
- Automatic RGBW mode when SK6812 is selected
- Supports both 3-channel (WS2812B, WS2811, WS2813) and 4-channel (SK6812) LEDs

#### Beacon Settings
- Independent RGBW checkbox for beacon strip
- Beacon LED type selector (separate from main LEDs)
- GIF preview updates dynamically with effect selection

### Technical Details

#### RGBW Implementation
- **Color Order**: GRBW (Green, Red, Blue, White) for SK6812
- **Bit Depth**: 32 bits per LED (RGBW) vs 24 bits (RGB)
- **RMT Driver**: Properly configured for both 3 and 4 channel LEDs
- **White Optimization**: Automatic when r==g==b
  ```cpp
  if (w == 0 && r > 0 && r == g && g == b) {
      rgbw_leds[i].w = r;
      rgbw_leds[i].r = rgbw_leds[i].g = rgbw_leds[i].b = 0;
  }
  ```

#### Mode Priority System
1. **Door Open Lights** (highest priority) - Works in all modes
2. **Manual Mode** - User control, ignores printer state
3. **Auto Mode** - Color cycling, ignores printer state
4. **Printer Mode** - Follows printer state (pauses during door open)
5. **Off Mode** - All LEDs off (except door lights)

### Flash Usage
- Current: 96.8% (1,269,225 / 1,310,720 bytes)
- Filesystem: ~1.5MB (default.csv partition)
- GIF Assets: ~51KB total

### Testing Notes
- Tested with SK6812 RGBW LED strips
- Verified white channel usage with scope/multimeter
- Confirmed mode isolation (MANUAL/AUTO don't respond to printer)
- Validated door open protection during jogging
- All 4 beacon GIFs switching correctly

### Python Dependencies (for GIF generation)
```
Pillow >= 10.0.0
numpy >= 1.24.0
```

### Known Limitations
- GIF animations are static files (not generated in real-time)
- Beacon strip configuration separate from main LED configuration
- White channel optimization only for equal RGB values (gray/white colors)

---

## Upgrade Notes

If upgrading from previous version:
1. Select "SK6812 (RGBW Compatible)" in LED Type if using RGBW strips
2. Upload all 4 GIF files to `/data/` directory via LittleFS
3. Configure beacon RGBW checkbox if beacon uses 4-channel LEDs
4. Test door open behavior in PRINTER mode to ensure no flickering during jogging

---

## Future Enhancements (Suggestions)
- Real-time beacon effect rendering (eliminate need for GIF files)
- Configurable white channel threshold (currently r==g==b)
- Per-state RGBW/RGB mode override
- Additional beacon effect animations

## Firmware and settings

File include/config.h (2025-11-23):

#ifndef CONFIG_H
#define CONFIG_H

// Hardware Configuration
#define LED_PIN 2
#define DEFAULT_LED_COUNT 36
#define MAX_LED_COUNT 256
#define MIN_LED_COUNT 1

// Beacon LED Configuration
#define BEACON_LED_PIN 14
#define DEFAULT_BEACON_LED_COUNT 10
#define MAX_BEACON_LED_COUNT 50
#define MIN_BEACON_LED_COUNT 1

// Network Configuration
#define WIFI_CONNECT_TIMEOUT_MS 20000
#define MQTT_RECONNECT_INTERVAL_MS 5000
#define MQTT_KEEPALIVE_INTERVAL_S 60

// Memory Management
#define JSON_BUFFER_SIZE 4096
#define MQTT_MESSAGE_BUFFER_SIZE 16384
#define WS_MESSAGE_BUFFER_SIZE 2048
#define CONFIG_STRING_MAX_LENGTH 64

// Task Configuration
#define LED_TASK_STACK_SIZE 4096
#define WIFI_TASK_STACK_SIZE 4096
#define MQTT_TASK_STACK_SIZE 8192
#define WS_TASK_STACK_SIZE 4096

// Security Configuration
#define AP_PASSWORD_LENGTH 32
#define DEVICE_ID_LENGTH 16

// EEPROM Configuration
#define EEPROM_SIZE 4096
#define EEPROM_COMMIT_INTERVAL_MS 300000  // 5 minutes instead of 1 minute
#define CONFIG_MAGIC_BYTES 0x42414D42      // "BAMB"

// Timing Configuration
#define LED_UPDATE_INTERVAL_MS 33          // ~30 FPS
#define HEARTBEAT_INTERVAL_MS 10000
#define WATCHDOG_TIMEOUT_MS 30000

// Error Handling
#define MAX_RECONNECT_ATTEMPTS 10
#define RECONNECT_BACKOFF_MAX_MS 60000

// Debug Configuration - declarations only, implementations in main.cpp
#ifdef DEBUG
void debug_print(const char* str);
void debug_println(const char* str);
void debug_printf(const char* fmt, ...);
#define DEBUG_PRINT(x) debug_print(x)
#define DEBUG_PRINTLN(x) debug_println(x)
#define DEBUG_PRINTF(fmt, ...) debug_printf(fmt, ##__VA_ARGS__)
#else
#define DEBUG_PRINT(x)
#define DEBUG_PRINTLN(x)
#define DEBUG_PRINTF(fmt, ...)
#endif

// Validation Macros
#define VALIDATE_BUFFER_SIZE(size, max_size) \
    do { \
        if ((size) > (max_size)) { \
            DEBUG_PRINTF("Buffer overflow prevented: %zu > %zu\n", (size_t)(size), (size_t)(max_size)); \
            return false; \
        } \
    } while(0)

#define SAFE_STRING_COPY(dest, src, max_len) \
    do { \
        strncpy((dest), (src), (max_len) - 1); \
        (dest)[(max_len) - 1] = '\0'; \
    } while(0)

#endif // CONFIG_H

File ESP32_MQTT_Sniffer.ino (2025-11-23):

/*
 * ESP32 Bambu Lab MQTT Sniffer
 * 
 * This sketch connects to your Bambu Lab printer's MQTT broker and dumps
 * all messages to Serial for capture and analysis.
 * 
 * Instructions:
 * 1. Update WiFi credentials below
 * 2. Update printer IP, access code, and serial number
 * 3. Upload to ESP32 (any variant - NodeMCU-32S, DevKitC, etc.)
 * 4. Open Serial Monitor at 115200 baud
 * 5. Use a serial capture tool to save output to .txt file
 * 
 * Hardware: ESP32 (any variant)
 * 
 * Required Libraries (install via Arduino Library Manager):
 * - WiFi (built-in with ESP32 board support)
 * - PubSubClient by Nick O'Leary
 * 
 * Board Selection: Tools -> Board -> ESP32 Arduino -> ESP32 Dev Module (or your board)
 */

#include <WiFi.h>
#include <WiFiClientSecure.h>
#include <PubSubClient.h>

// ======================== CONFIGURATION ========================
// WiFi Settings
const char* WIFI_SSID = "YourWiFiSSID";           // Your WiFi network name
const char* WIFI_PASSWORD = "YourWiFiPassword";   // Your WiFi password

// Bambu Lab Printer Settings
const char* MQTT_SERVER = "192.168.0.100";        // Your printer's IP address
const int MQTT_PORT = 8883;                        // SSL port (8883) or non-SSL (1883)
const char* MQTT_USERNAME = "bblp";                // Always "bblp" for Bambu Lab
const char* MQTT_PASSWORD = "12345678";            // Your printer's access code
const char* DEVICE_SERIAL = "01S00A123456789";     // Your printer's serial number

const bool USE_SSL = true;                         // Use SSL/TLS (true for port 8883)
// ===============================================================

WiFiClientSecure wifiClientSecure;
WiFiClient wifiClient;
PubSubClient mqttClient;

unsigned long lastReconnect = 0;
unsigned long messageCount = 0;

void setup() {
  // Start serial at high speed for fast capture
  Serial.begin(115200);
  delay(100);
  
  Serial.println("\n\n");
  Serial.println("========================================");
  Serial.println("  ESP8266 Bambu Lab MQTT Sniffer");
  Serial.println("========================================");
  Serial.println();
  
  // Connect to WiFi
  Serial.print("Connecting to WiFi: ");
  Serial.println(WIFI_SSID);
  
  WiFi.mode(WIFI_STA);
  WiFi.begin(WIFI_SSID, WIFI_PASSWORD);
  
  while (WiFi.status() != WL_CONNECTED) {
    delay(500);
    Serial.print(".");
  }
  
  Serial.println();
  Serial.println("WiFi connected!");
  Serial.print("IP address: ");
  Serial.println(WiFi.localIP());
  Serial.println();
  
  // Configure MQTT client
  if (USE_SSL) {
    wifiClientSecure.setInsecure(); // Skip certificate verification (like Bambu does)
    mqttClient.setClient(wifiClientSecure);
  } else {
    mqttClient.setClient(wifiClient);
  }
  
  mqttClient.setServer(MQTT_SERVER, MQTT_PORT);
  mqttClient.setCallback(mqttCallback);
  mqttClient.setBufferSize(32768); // 32KB buffer (ESP32 has plenty of RAM)
  
  Serial.println("Configuration:");
  Serial.print("  MQTT Server: ");
  Serial.println(MQTT_SERVER);
  Serial.print("  MQTT Port: ");
  Serial.println(MQTT_PORT);
  Serial.print("  SSL/TLS: ");
  Serial.println(USE_SSL ? "Enabled" : "Disabled");
  Serial.print("  Device Serial: ");
  Serial.println(DEVICE_SERIAL);
  Serial.println();
  Serial.println("========================================");
  Serial.println();
  
  // Initial connection
  connectMQTT();
}

void loop() {
  // Maintain MQTT connection
  if (!mqttClient.connected()) {
    unsigned long now = millis();
    if (now - lastReconnect > 5000) { // Try reconnect every 5 seconds
      lastReconnect = now;
      connectMQTT();
    }
  } else {
    mqttClient.loop();
  }
  
  // Yield to allow ESP8266 background tasks
  yield();
}

void connectMQTT() {
  Serial.println("Connecting to MQTT broker...");
  Serial.print("  Server: ");
  Serial.print(MQTT_SERVER);
  Serial.print(":");
  Serial.println(MQTT_PORT);
  
  // Generate unique client ID
  String clientId = "ESP8266-Sniffer-";
  clientId += String(random(0xffff), HEX);
  
  // Connect with username and password
  if (mqttClient.connect(clientId.c_str(), MQTT_USERNAME, MQTT_PASSWORD)) {
    Serial.println("MQTT Connected!");
    
    // Subscribe to all printer topics
    String reportTopic = "device/" + String(DEVICE_SERIAL) + "/report";
    
    if (mqttClient.subscribe(reportTopic.c_str(), 0)) {
      Serial.print("Subscribed to: ");
      Serial.println(reportTopic);
    } else {
      Serial.println("ERROR: Failed to subscribe!");
    }
    
    Serial.println();
    Serial.println("========================================");
    Serial.println("  Listening for MQTT messages...");
    Serial.println("  Start your timelapse print now!");
    Serial.println("========================================");
    Serial.println();
    
  } else {
    Serial.print("MQTT connection failed, rc=");
    Serial.println(mqttClient.state());
    Serial.println("Error codes:");
    Serial.println("  -4 : MQTT_CONNECTION_TIMEOUT");
    Serial.println("  -3 : MQTT_CONNECTION_LOST");
    Serial.println("  -2 : MQTT_CONNECT_FAILED");
    Serial.println("  -1 : MQTT_DISCONNECTED");
    Serial.println("   1 : MQTT_CONNECT_BAD_PROTOCOL");
    Serial.println("   2 : MQTT_CONNECT_BAD_CLIENT_ID");
    Serial.println("   3 : MQTT_CONNECT_UNAVAILABLE");
    Serial.println("   4 : MQTT_CONNECT_BAD_CREDENTIALS");
    Serial.println("   5 : MQTT_CONNECT_UNAUTHORIZED");
    Serial.println();
  }
}

void mqttCallback(char* topic, byte* payload, unsigned int length) {
  messageCount++;
  
  // Print message separator
  Serial.println();
  Serial.println("╔═══════════════════════════════════════════════════════════");
  Serial.print("║ MESSAGE #");
  Serial.println(messageCount);
  Serial.println("╟───────────────────────────────────────────────────────────");
  
  // Print timestamp
  Serial.print("║ Time: ");
  Serial.print(millis() / 1000);
  Serial.println(" seconds");
  
  // Print topic
  Serial.print("║ Topic: ");
  Serial.println(topic);
  
  // Print payload length
  Serial.print("║ Length: ");
  Serial.print(length);
  Serial.println(" bytes");
  
  Serial.println("╟───────────────────────────────────────────────────────────");
  Serial.println("║ PAYLOAD:");
  Serial.println("╟───────────────────────────────────────────────────────────");
  
  // Print the full payload
  for (unsigned int i = 0; i < length; i++) {
    Serial.print((char)payload[i]);
  }
  
  Serial.println();
  Serial.println("╚═══════════════════════════════════════════════════════════");
  Serial.println();
  
  // Flush serial buffer to ensure everything is sent
  Serial.flush();
  
  // Print a summary line for easy grepping
  Serial.print("SUMMARY: MSG#");
  Serial.print(messageCount);
  Serial.print(" | Time=");
  Serial.print(millis() / 1000);
  Serial.print("s | Size=");
  Serial.print(length);
  Serial.print("B | Topic=");
  Serial.println(topic);
  Serial.println();
}

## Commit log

2025-11-23 Initial commit: Bambu Lights - Advanced LED Controller for Bambu Lab printers
2025-11-23 Add beacon LED effect demos to README
2025-12-13 Add telnet support, fix chunked HTTP crash, add home automation docs and enclosure README
2025-12-13 Add beacon enclosure STL and Fusion 360 files
    - 10 led cover.stl: Top cover for LED strip
    - 10 led holder fits ams riser.stl: Mounting bracket for AMS riser
    - 10 led insert holder.stl: LED strip insert holder
    - Beacon.f3d: Fusion 360 source file for enclosure design
    [10 led cover.stl, 10 led holder fits ams riser.stl, 10 led insert holder.stl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]
2025-12-13 Update 10 led cover.stl with design improvements
    [10 led cover.stl]
2025-12-13 Add LAN-only mode notification benefits section to README
    Highlights that MQTT integration provides push notifications, SMS, email, and TTS announcements when printer is in LAN-only mode (no cloud connection), replacing lost Bambu Handy app features.
